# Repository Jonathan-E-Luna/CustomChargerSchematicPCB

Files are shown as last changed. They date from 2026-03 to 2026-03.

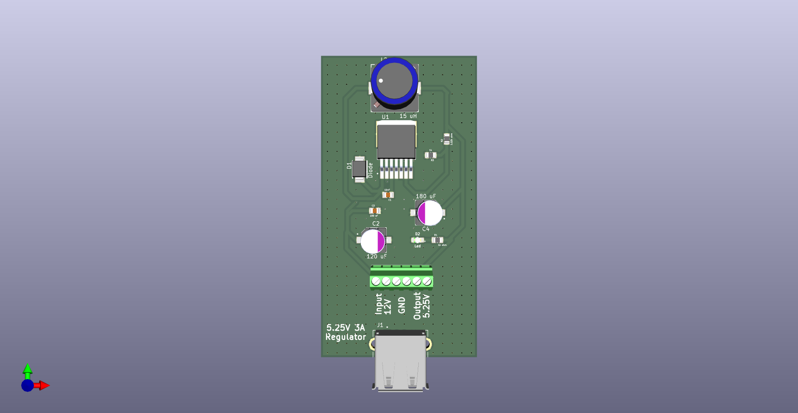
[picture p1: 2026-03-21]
Rasp_Reg.png

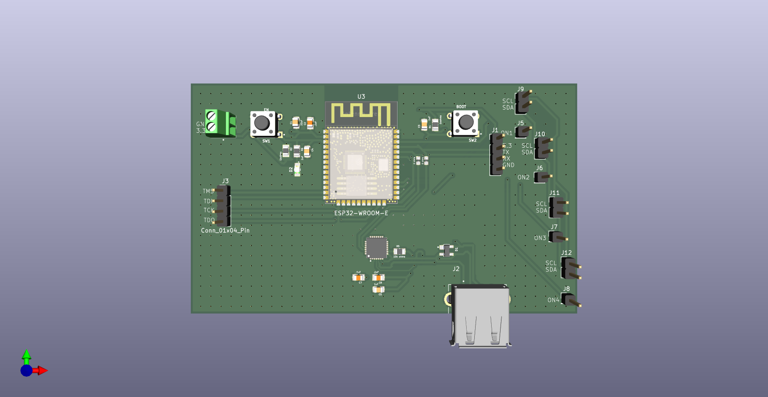
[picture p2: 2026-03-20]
MCU.png

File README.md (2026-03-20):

# CustomChargerSchematicPCB
During my groups capstone, I was in charge of the PCB design for all custom hardware components utilized. The boards are subdivided into three main catagories
1) Power boards- These boards are Switching Regulators designed to power the microcontronller, Current Switch Board (Will be mentioned later) and a raspberry pi module. Since all power boards use the same switch regulator IC, only one is shown
2) MCU Board - This board houses an ESP-32 Microcontroller that will controll the Current/Voltage measurement IC (INA260) and the Load Switch TPS22918
3) Current Switch Board - Houses the INA260 and TPS22918 that will take current from the 5V regulator and deliver power to a load.

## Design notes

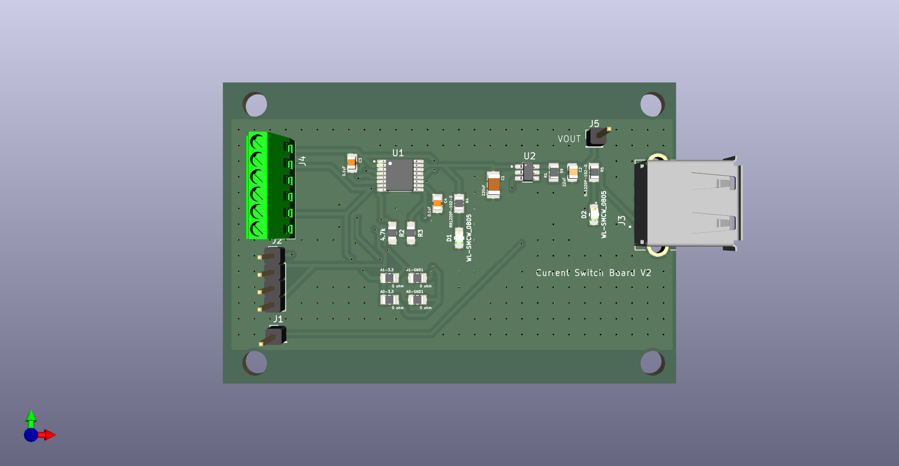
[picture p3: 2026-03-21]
Current Switch.png

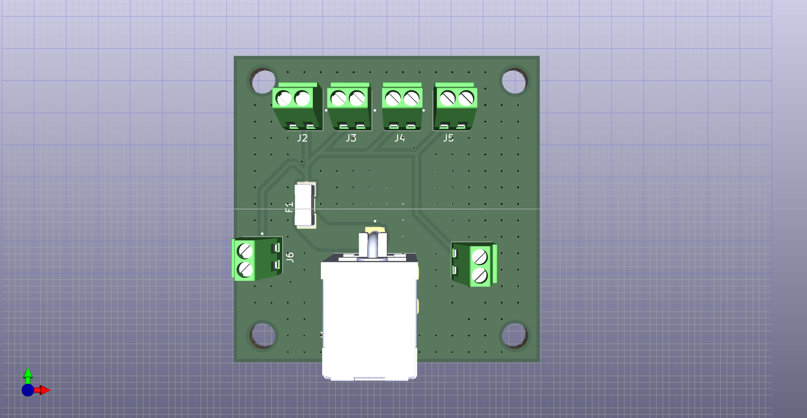
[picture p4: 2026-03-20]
DC JACK.png

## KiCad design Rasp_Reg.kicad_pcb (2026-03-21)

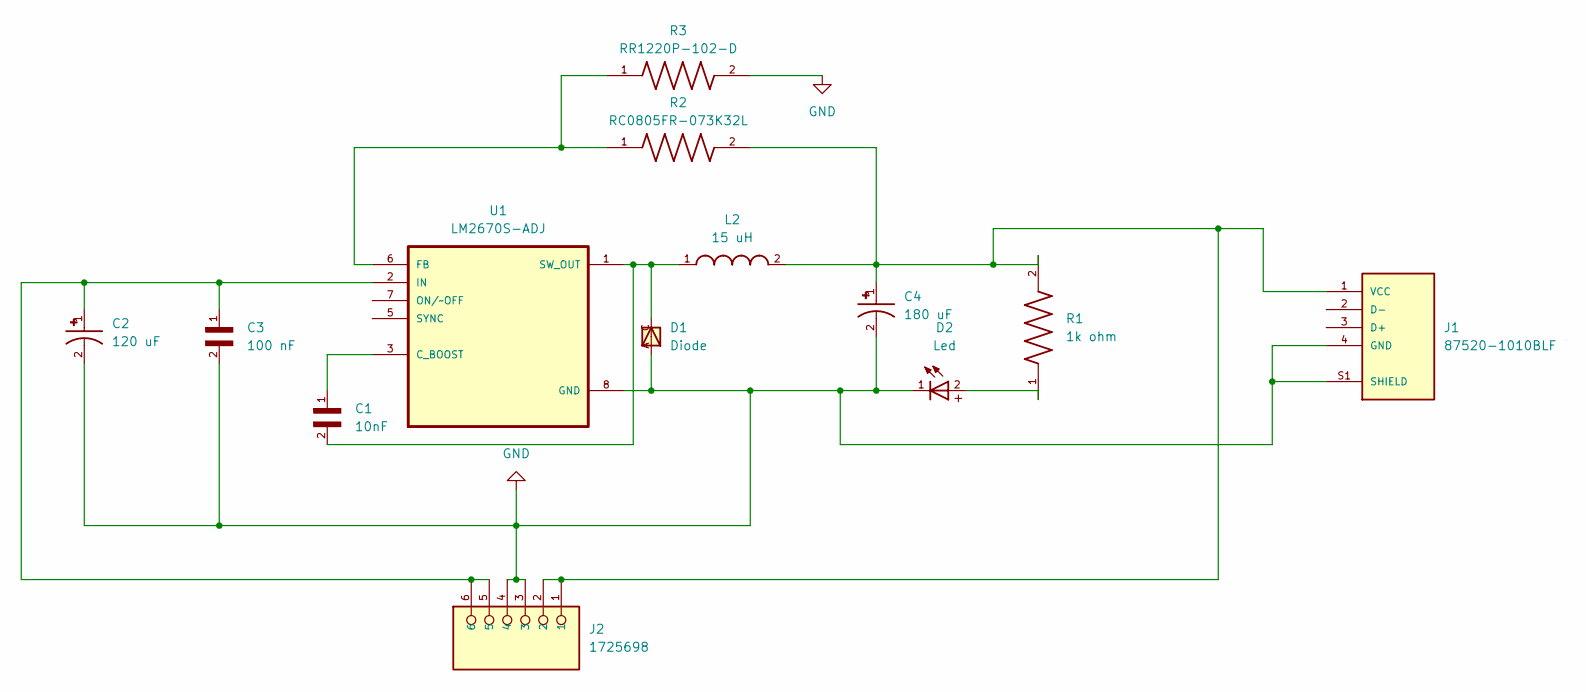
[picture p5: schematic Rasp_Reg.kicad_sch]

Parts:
C1: 10nF; CAPC2012X75N
C2: 120 uF; CAP_20SVPF120M; PARTREV 28-Jun-19
C3: 100 nF; CAPC2012X94N
C4: 180 uF; CAP_16SVPE180M; PARTREV 05-Mar-21
D1: Diode; SMB
D2: Led; WL-SMCW_0805
J1: 87520-1010BLF; AMPHENOL_87520-1010BLF; PARTREV AR
J2: 1725698; PHOENIX_1725698; PARTREV 03.03.2021
L2: 15 uH; INDP125125X785N
R1: 1k ohm; RESC2012X50N
R2: RC0805FR-073K32L; RESC2012X60N
R3: RR1220P-102-D; RESC2012X50N
U1: LM2670S-ADJ; TO127P1435X464-8N

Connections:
GND: C2.2, C3.2, C4.2, D1.A, D2.1, J1.4 (GND), J1.S1 (SHIELD), J1.S2 (SHIELD), J2.3, J2.4, R3.2, U1.4 (GND), U1.8 (GND)
unnamed: D2.2, R1.1
unnamed: C4.1, J1.1 (VCC), J2.1, J2.2, L2.2, R1.2, R2.2
unnamed: C1.1, U1.3 (C_BOOST)
unnamed: R2.1, R3.1, U1.6 (FB)
unnamed: C2.1, C3.1, J2.5, J2.6, U1.2 (IN)
unnamed: C1.2, D1.C, L2.1, U1.1 (SW_OUT)

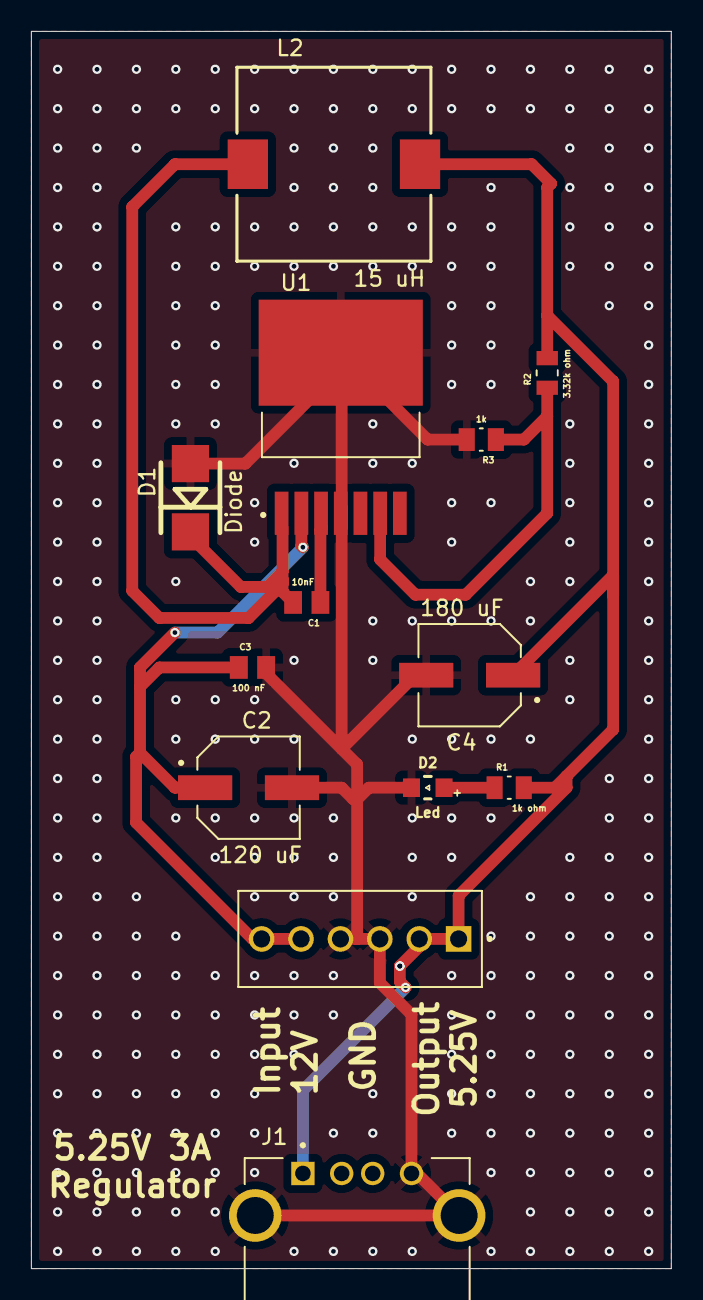
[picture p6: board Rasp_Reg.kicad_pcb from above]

Board: 2 copper layers, 41.2 x 79.8 mm, 13 parts (0 on the bottom side), 7 nets.

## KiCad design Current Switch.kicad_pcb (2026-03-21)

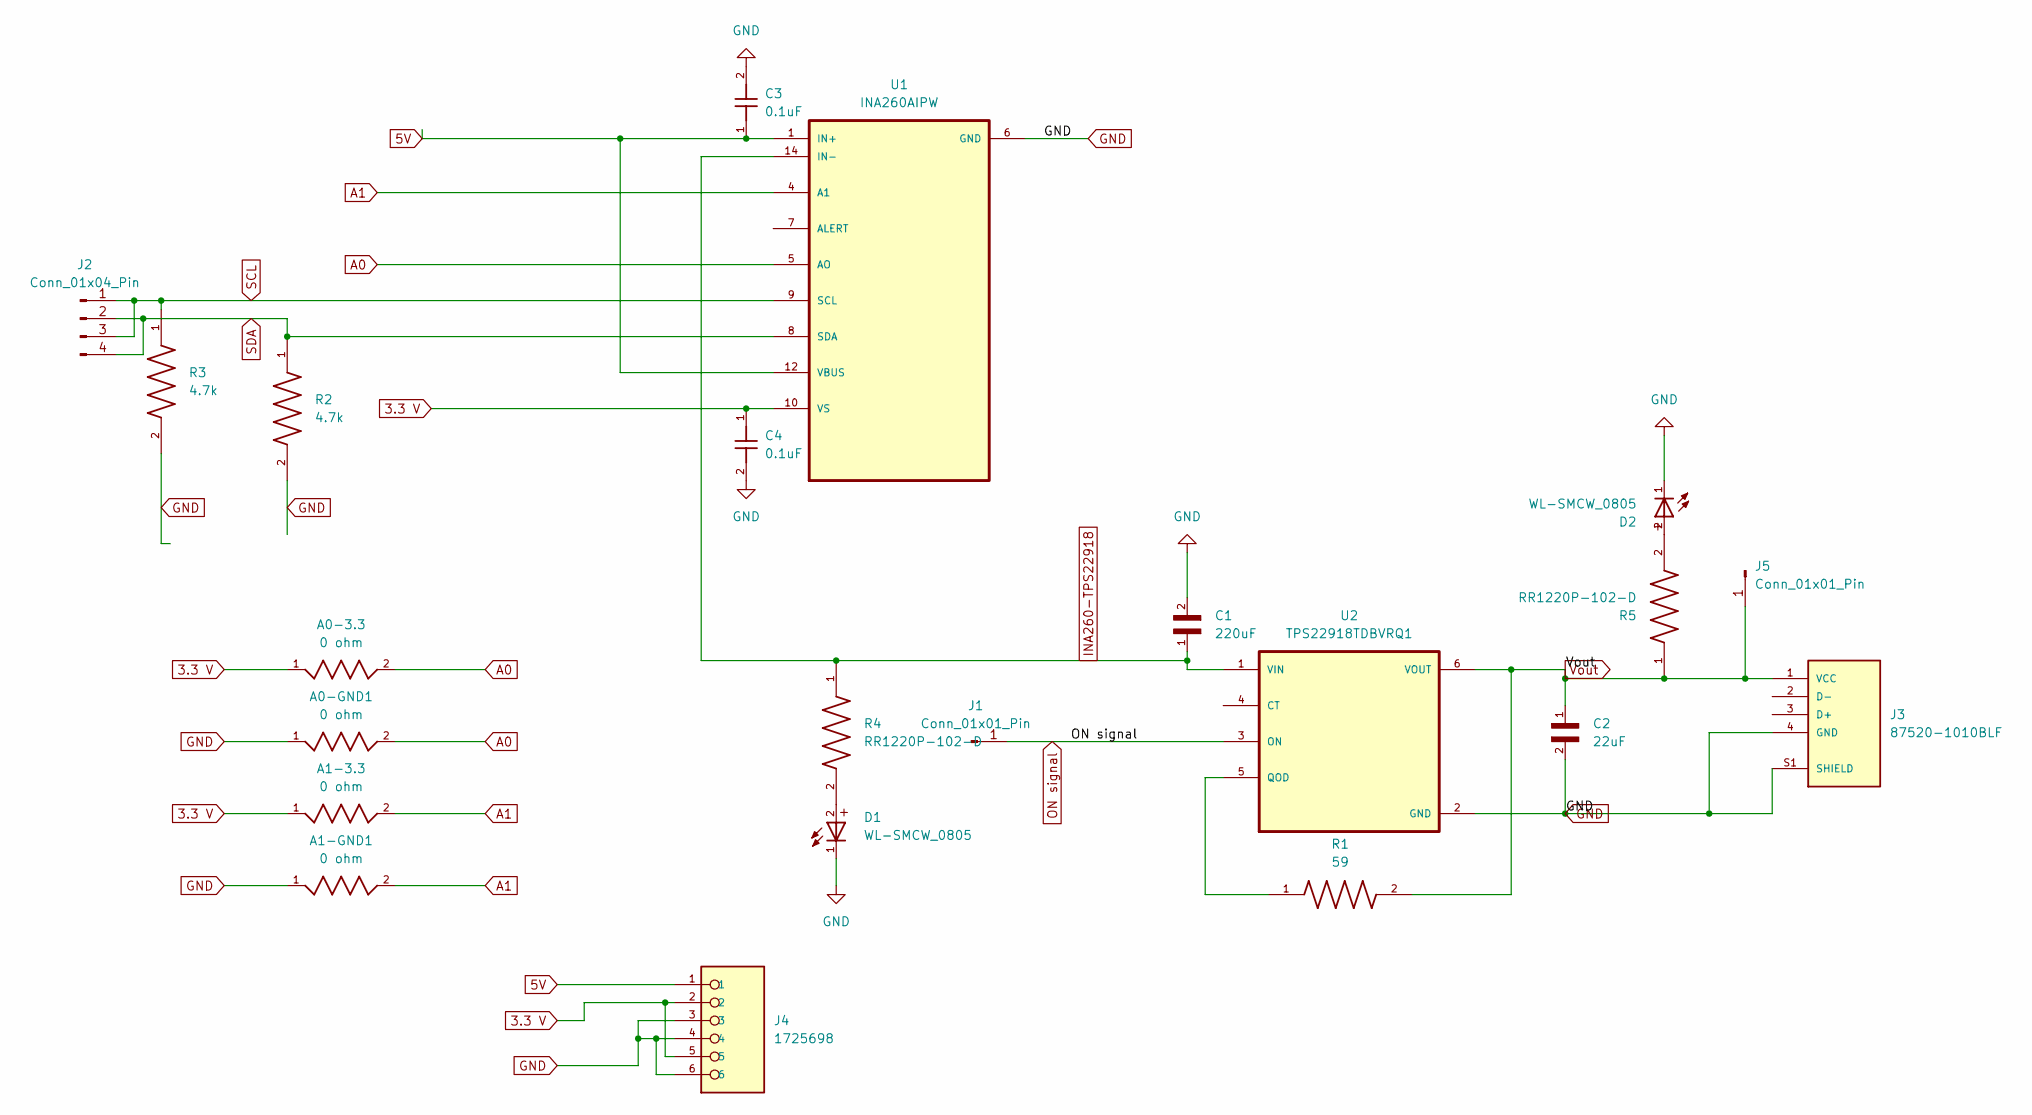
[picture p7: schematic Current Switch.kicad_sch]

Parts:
A0-3.3, A0-GND1, A1-3.3, A1-GND1: 0 ohm; RESC2012X60N; PARTREV V.12
C1: 220uF; CAPC3216X190N
C2: 22uF; CAPC2012X140N
C3, C4: 0.1uF; CAPC2012X88N
D1, D2: WL-SMCW_0805
J1, J5: Conn_01x01_Pin; PinHeader_1x01_P2.54mm_Vertical
J2: Conn_01x04_Pin; PinHeader_1x04_P2.54mm_Vertical
J3: 87520-1010BLF; AMPHENOL_87520-1010BLF; PARTREV AR
J4: 1725698; PHOENIX_1725698; PARTREV 03.03.2021
R1: 59; RESC2012X50N
R2, R3: 4.7k; RES_ERA6AEB472V; PARTREV 3/1/2020
R4, R5: RR1220P-102-D; RESC2012X50N
U1: INA260AIPW; SOP65P640X120-16N
U2: TPS22918TDBVRQ1; SOT95P280X145-6N

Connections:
3.3 V: A0-3.3.1, A1-3.3.1, C4.1, J4.2, J4.5, U1.10 (VS)
5V: C3.1, J4.1, U1.1 (IN+), U1.2 (IN+), U1.3 (IN+), U1.12 (VBUS)
A0: A0-3.3.2, A0-GND1.2, U1.5 (AO)
A1: A1-3.3.2, A1-GND1.2, U1.4 (A1)
GND: A0-GND1.1, A1-GND1.1, C1.2, C2.2, C3.2, C4.2, D1.1, D2.1, J3.4 (GND), J3.S1 (SHIELD), J3.S2 (SHIELD), J4.3, J4.4, J4.6, R2.2, R3.2, U1.6 (GND), U1.11 (GND), U2.2 (GND)
INA260-TPS22918: C1.1, R4.1, U1.14 (IN-), U1.15 (IN-), U1.16 (IN-), U2.1 (VIN)
unnamed: D1.2, R4.2
unnamed: D2.2, R5.2
unnamed: R1.1, U2.5 (QOD)
ON signal: J1.1, U2.3 (ON)
SCL: J2.1, J2.3, R3.1, U1.9 (SCL)
SDA: J2.2, J2.4, R2.1, U1.8 (SDA)
Vout: C2.1, J3.1 (VCC), J5.1, R1.2, R5.1, U2.6 (VOUT)

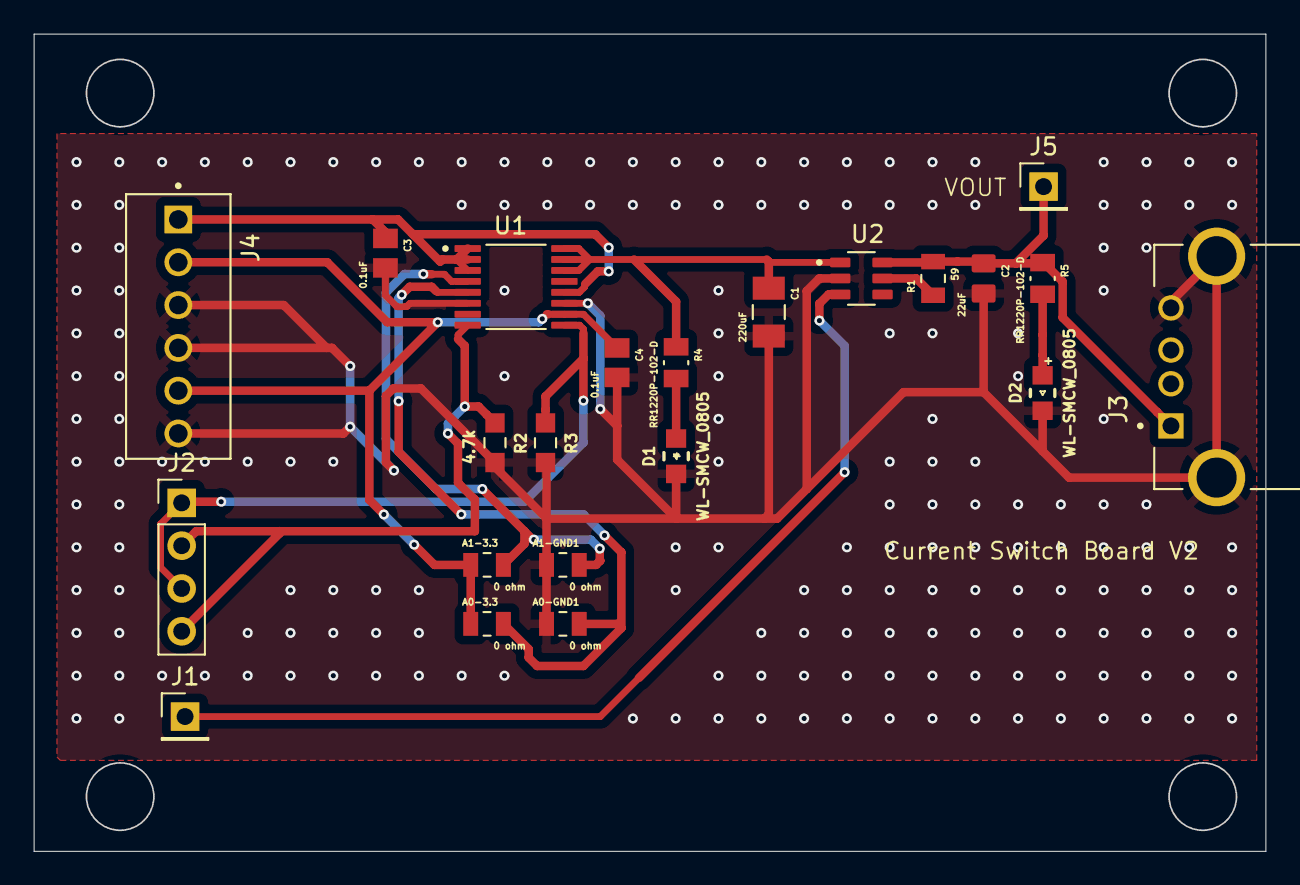
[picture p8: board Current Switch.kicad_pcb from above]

Board: 2 copper layers, 73.1 x 48.5 mm, 22 parts (0 on the bottom side), 13 nets.

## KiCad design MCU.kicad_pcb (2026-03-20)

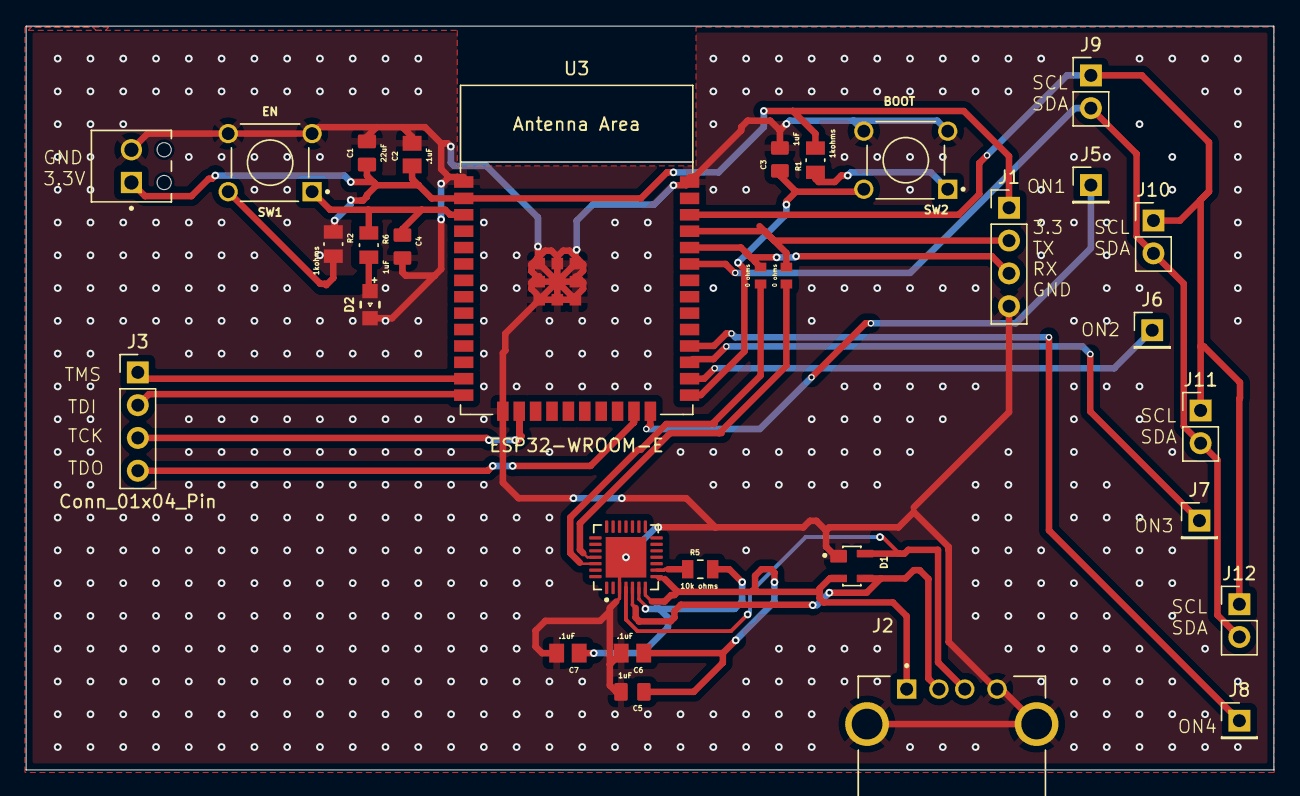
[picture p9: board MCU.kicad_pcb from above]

Board: 2 copper layers, 96.7 x 57.6 mm, 31 parts (0 on the bottom side), 26 nets.

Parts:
C1: 22uF; CAPC2012X140N
C2, C6, C7: .1uF; CAPC2012X88N
C3, C4, C5: 1uF; CAPC2012X135N
D1: SP0503BAHTG; SOT143
D2: WL-SMCW_0805
J1, J3: Conn_01x04_Pin; PinHeader_1x04_P2.54mm_Vertical
J2: 87520-1010BLF; AMPHENOL_87520-1010BLF
J4: 1725656; PHOENIX_1725656
J5: ON1; PinHeader_1x01_P2.54mm_Vertical
J6: ON2; PinHeader_1x01_P2.54mm_Vertical
J7: ON3; PinHeader_1x01_P2.54mm_Vertical
J8: ON4; PinHeader_1x01_P2.54mm_Vertical
J9: ON1; PinHeader_1x02_P2.54mm_Vertical
J10, J11, J12: Conn_01x02_Pin; PinHeader_1x02_P2.54mm_Vertical
R1, R2, R6: 1kohms; RESC2012X50N
R3, R4: 0 ohms; RESC1005X40
R5: 10k ohms; RESC2012X60N
SW1: EN; SW_1825910-6-4
SW2: BOOT; SW_1825910-6-4
U2: CP2102-GM; QFN50P500X500X100-29N
U3: ESP32-WROOM-E; ESP32-WROOM-32E

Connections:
BOOT: C3.1, SW2.2, U3.25 (GPIO0/BOOT/ADC2_CH1)
EN: C4.1, R6.1, SW1.1, U3.3 (EN/CHIP_PU)
GND: C1.2, C2.2, C3.2, C4.2, C5.2, C6.2, C7.2, D1.1, D2.1, J1.4, J2.4 (GND), J2.S1 (SHIELD), J2.S2 (SHIELD), J4.2, SW1.3, SW1.4, SW2.3, SW2.4, U2.3 (GND), U2.29 (GND), U3.1 (GND), U3.15 (GND), U3.38 (GND), U3.39 (GND_THERMAL)
unnamed: D2.2, R6.2
unnamed: D1.4, J2.3 (D+), U2.4 (D+)
unnamed: D1.3, J2.2 (D-), U2.5 (D–)
unnamed: R1.1, SW2.1
unnamed: R2.2, SW1.2
unnamed: R3.2, U2.25 (RXD)
unnamed: R4.1, U2.26 (TXD)
unnamed: C7.1, R5.2, U2.6 (VDD)
unnamed: R5.1, U2.9 (~RST)
ON 1: J5.1, U3.24 (ADC2_CH2/GPIO2)
ON 2: J6.1, U3.26 (ADC2_CH0/GPIO4)
ON 3: J7.1, U3.27 (GPIO16)
ON 4: J8.1, U3.28 (GPIO17)
RX: J1.3, R4.2, U3.34 (U0RXD/GPIO3)
SCL: J9.1, J10.1, J11.1, J12.1, U3.36 (GPIO22)
SDA: J9.2, J10.2, J11.2, J12.2, U3.33 (GPIO21)
TCK: J3.3, U3.16 (MTCK/GPIO13/ADC2_CH4)
TDI: J3.2, U3.14 (MTDI/GPIO12/ADC2_CH5)
TDO: J3.4, U3.23 (MTDO/GPIO15/ADC2_CH3)
TMS: J3.1, U3.13 (MTMS/GPIO14/ADC2_CH6)
TX: J1.2, R3.1, U3.35 (U0TXD/GPIO1)
VBUS: C5.1, C6.1, D1.2, J2.1 (VCC), U2.7 (REGIN), U2.8 (VBUS)
VDD33: C1.1, C2.1, J1.1, J4.1, R1.2, R2.1, U3.2 (3V3)

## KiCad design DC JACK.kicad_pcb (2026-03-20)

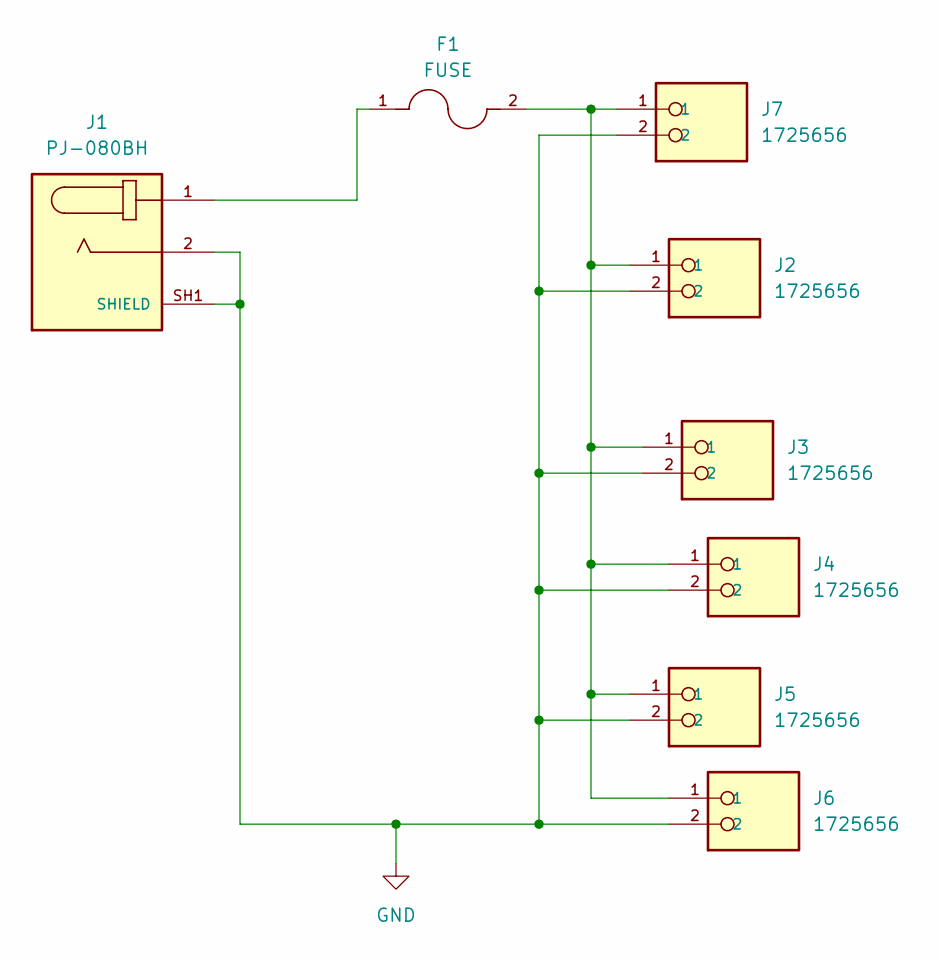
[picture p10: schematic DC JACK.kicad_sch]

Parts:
F1: FUSE; FUSC6125X279N; PARTREV 0679H Apr2019
J1: PJ-080BH; CUI_PJ-080BH; PARTREV 1.04
J2, J3, J4, J5, J6, J7: 1725656; PHOENIX_1725656; PARTREV 03.03.2021

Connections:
GND: J1.2, J1.SH1 (SHIELD), J1.SH2 (SHIELD), J1.SH3 (SHIELD), J1.SH4 (SHIELD), J2.2, J3.2, J4.2, J5.2, J6.2, J7.2
unnamed: F1.1, J1.1
unnamed: F1.2, J2.1, J3.1, J4.1, J5.1, J6.1, J7.1

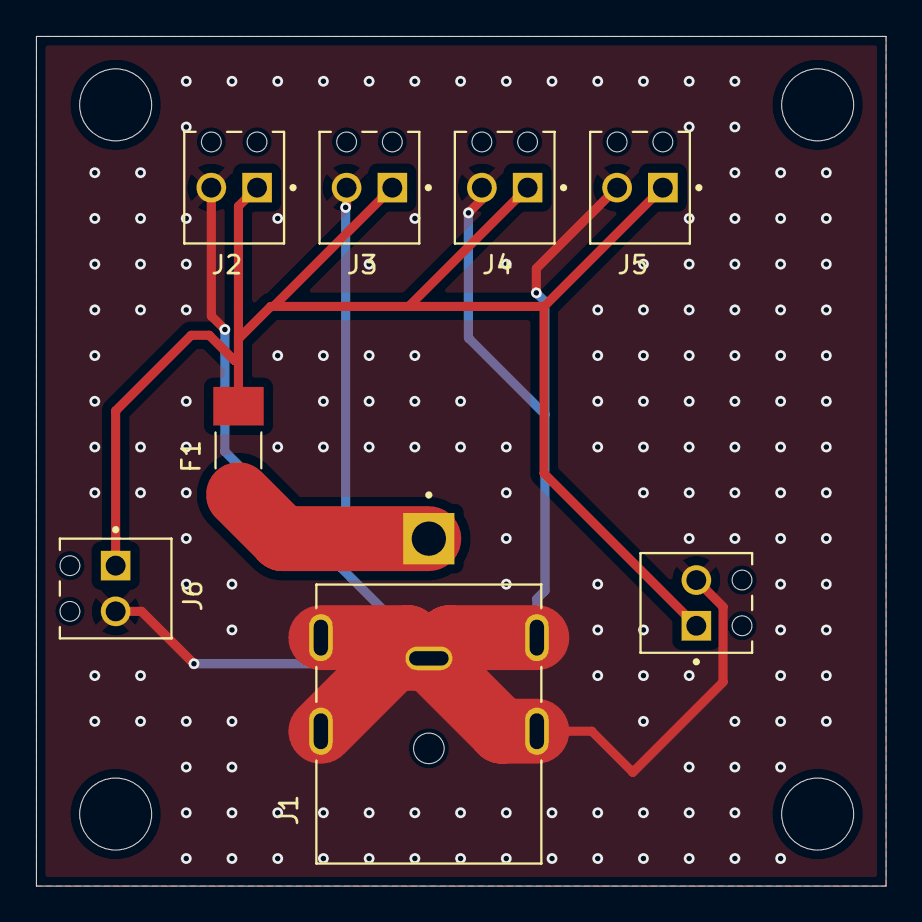
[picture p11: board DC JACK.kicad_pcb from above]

Board: 2 copper layers, 47.2 x 47.2 mm, 8 parts (0 on the bottom side), 3 nets.

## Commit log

2026-03-20 Enhance README with detailed PCB design categories
    Expanded description of PCB design and its components.
2026-03-20 Update description of Powerboard schematics
2026-03-20 Add files via upload
    All Schematics related to power regulation
    [3.3V regulator.kicad_sch, DC JACK.kicad_sch, Rasp_Reg.kicad_sch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]
2026-03-20 Update README with additional details on power boards
    Clarified description of power boards in README.
